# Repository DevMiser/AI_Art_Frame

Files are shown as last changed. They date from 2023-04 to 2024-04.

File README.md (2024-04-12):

On March 26, 2024, OpenAI updated its billing system to require the pre-purchase of credits in order to use the API for most users.  If you do not pre-purchase credits, you will get an API error.



















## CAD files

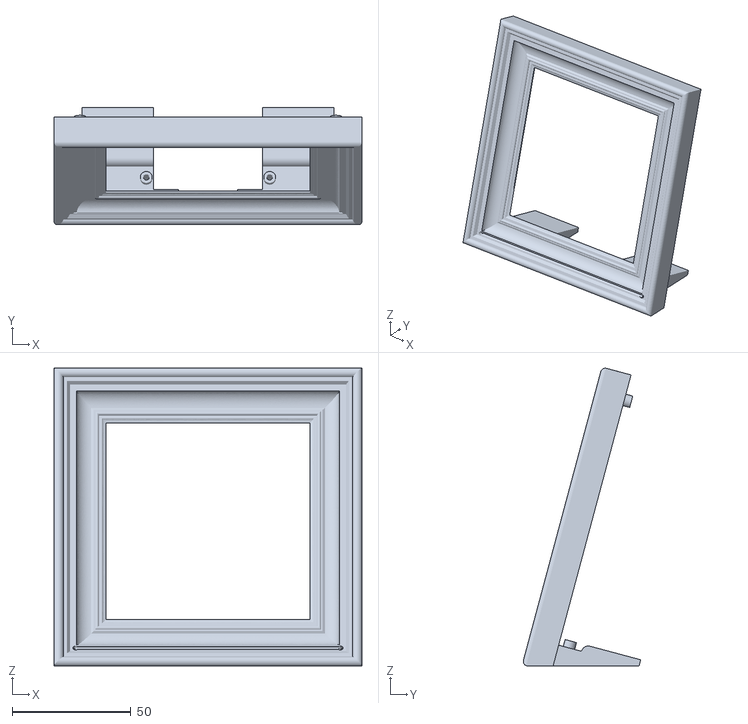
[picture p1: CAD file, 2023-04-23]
AI Art Frame.stl
129.8 x 49.5 x 125.4

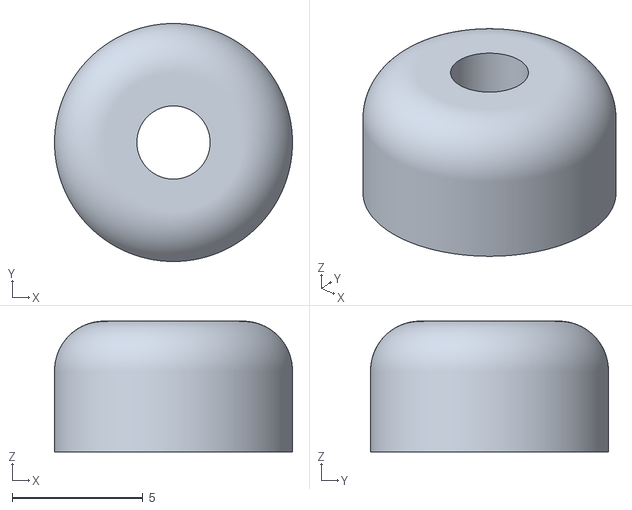
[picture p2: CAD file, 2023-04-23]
Display Stabilizer Plain.stl
9.10 x 9.10 x 5.00

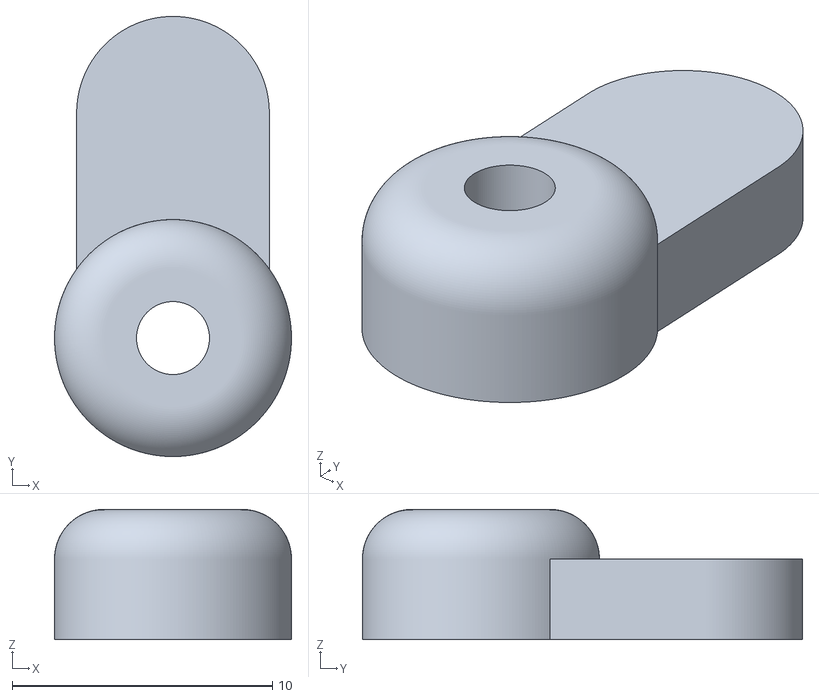
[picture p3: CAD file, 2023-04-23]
Display Stabilizer w Tab.stl
9.10 x 16.9 x 5.00

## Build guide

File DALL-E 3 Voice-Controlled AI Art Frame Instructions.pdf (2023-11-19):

## DALL-E 3 Voice-Controlled Artificial Intelligence Art Frame DIY Instructions

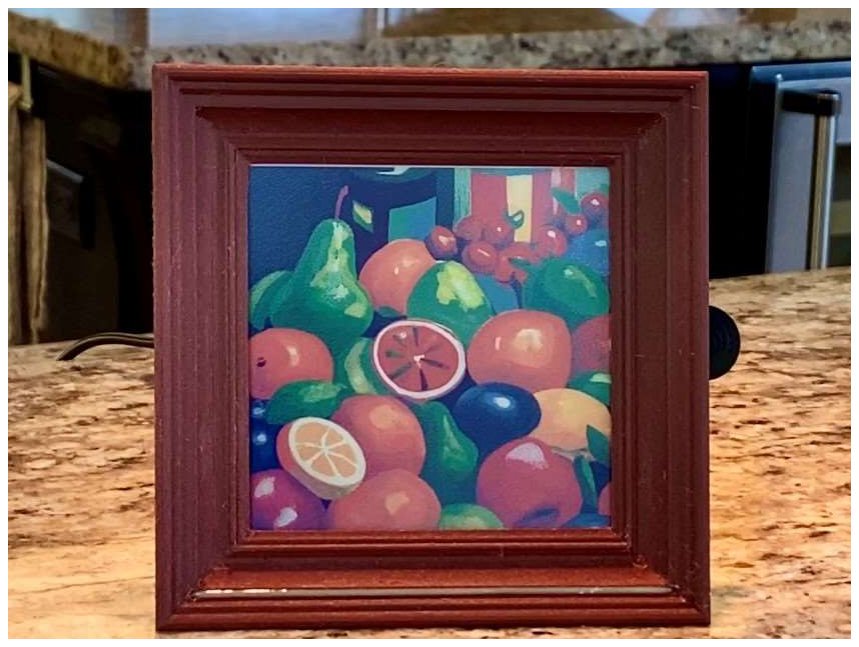
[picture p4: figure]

The DALL-E 3 Voice-Controlled AI Art Frame includes a 3D printed frame that houses a 7-color e-ink display and a Raspberry Pi 4. The RPi runs a python program that uses Picovoice Porcupine to detect a wake word; Picovoice Cobra voice activity detection to determine when the user begins and finishes speaking their image request; Picovoice Leopard to convert the spoken request into text; and OpenAI’s DALL-E 3 to convert the request to an image that is then displayed on a Pimoroni Inky Impression e-ink display.

The instructions below are for running the DALL-E 3 Voice-Controlled AI Art Frame on a Raspberry Pi 4, but it can also be run on other systems with minimal modifications. The process for obtaining access keys for DALL-E 3 and Picovoice solutions is the same regardless of the system used.

A brief video demo of the DALL-E 3 Voice-Controlled AI Art Frame is here: https://youtu.be/CKS973gClLE.

How to Run DALL-E 3 on a Raspberry Pi 4 Mini-Computer

The following steps are required to run the DALL-E3 AI image generator on your Raspberry Pi 4:

- Obtain the necessary hardware
- Create an OpenAI account and obtain your personal secret API key
- Create a Picovoice account and obtain your personal secret access key
- Follow the other steps below for preparing your Raspberry Pi and downloading the DALL-E 3 Voice-Controlled AI Art Frame

Hardware Requirements

Raspberry Pi 4 – This needs to be a Raspberry Pi 4, so that you can run the 64-bit operating system. Earlier versions of Raspberry Pis are likely to throw memory errors while running this program. The 2 GB RAM model is sufficient: https://www.adafruit.com/product/4292

Say something like “Art Frame, paint a still life of fruit,” and in a matter of
seconds an AI generated image depicting your request will ‘magically’ appear.

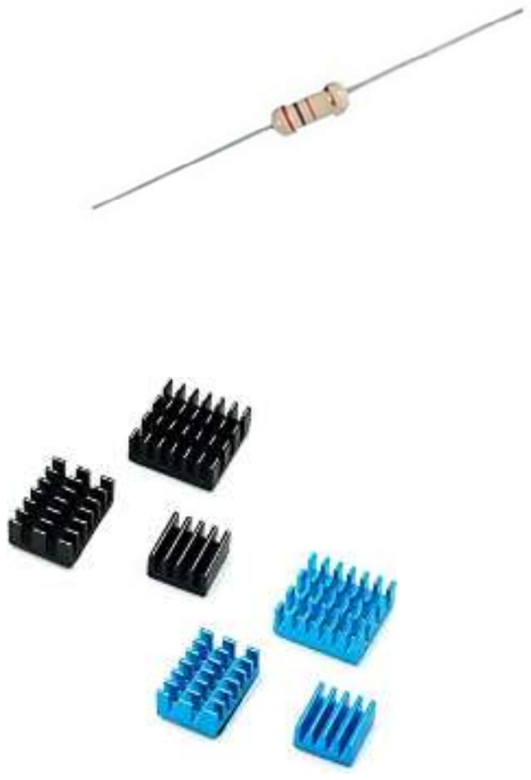
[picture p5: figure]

STLs for 3D-printing the DALL-E 3 Voice-Controlled AI Art Frame shown in the video demo are also available on this GitHub repository. See Appendix 1 for assembly instructions.

Create an OpenAI Account

Open a web browser on your PC and navigate to the OpenAI website -https://openai.com/.

In the upper right-hand corner, click on “API”

On the next screen, click on | and then follow the prompts to create your
account.

5v Power Supply – I recommend the official Raspberry Pi power supply: https://www.adafruit.com/product/4298

USB Microphone – for talking to the art frame. Any USB mic should work, and this inexpensive one is sufficient: https://www.adafruit.com/product/3367

Inky Impression 5.7” 7-color e-ink display – You can get one here: https://shop.pimoroni.com/en-us/products/inky-impression-5-7

LED Filament (300mm) – The program lights the LED filament when it detects the wake word and pulses it when the frame is responding to your request. This blue colored LED filament was used in the video demo: https://www.adafruit.com/product/5508

Resistor (220 ohm) – I used these: https://www.adafruit.com/product/2780

Heatsinks (recommended) – I used these: https://www.amazon.com/dp/B07ZLZRDXZ?psc=1&smid=A2PL6UUXJC5K5G&ref_=chk_typ_imgToDp

Obtain Your Secret OpenAI API Key

Next, on the logged-in screen, click on your Personal icon in the upper right-hand corner and then click on “View API keys”.

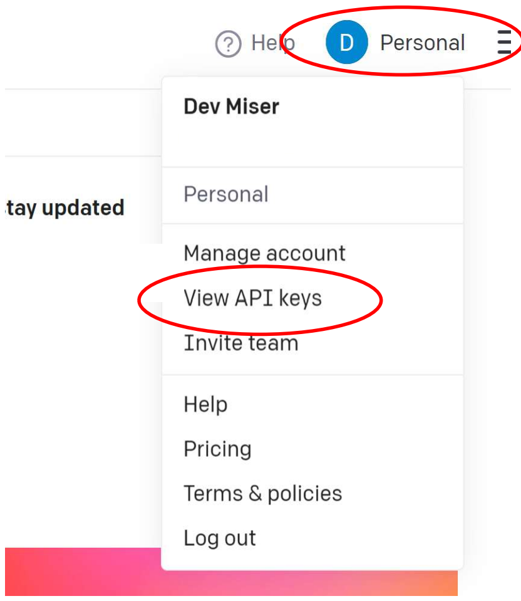
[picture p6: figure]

Then click on | to create your new secret API key. Copy your API key
and keep it in a secure location. You will need it in a later step.

Create a Picovoice Account

Create a free Picovoice account. Open a web browser and navigate to https://picovoice.ai/.
In the upper right-hand corner, click the | button and follow the prompts to open
your account.

Obtain Your Secret Picovoice Access Key

As soon as you complete your sign up, you will automatically be redirected to a page
with your secret access key. Copy your | and keep it in a secure location.
You will need it in a later step.

Prepare Your Raspberry Pi 4 to Run the Program

These instructions assume you already have a Raspberry Pi 4 set up and running. If not, set up your Raspberry Pi using the instructions found here: https://www.raspberrypi.com/tutorials/how-to-set-up-raspberry-pi/

Be certain to load the 64-bit (not the 32-bit) version of the Raspberry Pi OS when setting up your Raspberry Pi. If you use the 32-bit version, you are likely to get memory errors when running the program.

To prepare your Raspberry Pi to run the DALL-E 3 Voice-Controlled AI Art Frame, do the following:

### 1. Edit the bashrc file on your Raspberry Pi as follows:

a. Open a terminal and enter the following command to open the bashrc file:

sudo nano ~/.bashrc

b. Scroll to the bottom of the file using your keyboard and add the following lines at the end (be certain to include the #s):

# sets a location where the Raspberry Pi OS and Python can look for

# executable/configuration files

export PATH="$HOME/.local/bin:$PATH"
c. Press the CTRL and X keys simultaneously on your keyboard, then press Y and then press Enter to save the revisions to the file.
d. Then enter the following command:

sudo reboot

This will reboot your Raspberry Pi. After the reboot is completed, log back in.

### 2. Open a terminal and enter the following commands in the following order:

sudo apt update

sudo apt full-upgrade - If asked if you want to continue, enter Y and then press Enter

pip3 install --upgrade pip

sudo apt-get install portaudio19-dev - When asked if you want to continue, enter Y and then press Enter

pip3 install pyaudio

pip3 install pvrecorder

pip3 install pvporcupine

pip3 install pvcobra

pip3 install pvleopard

pip3 install schedule

pip3 install inky[rpi,example-depends]

pip3 install --upgrade openai

sudo reboot – will reboot your Raspberry Pi; log back in after the reboot.

### 3. Enable the SPI and I2C interfaces as follows:

a. Open a terminal and enter the following command:

sudo raspi-config

b. Using the arrows on your keyboard, scroll down to “3 Interface Options” and press Enter
c. Scroll down to “I4 SPI” and press Enter
d. The next screen will ask “Would you like the SPI interface to be enabled?” Select “Yes” and press Enter.
e. The next screen will state “The SPI interface in enabled”. Select “Ok” and press Enter.
f. Scroll down to “3 Interface Options” and press Enter
g. Scroll down to “I5 I2C” and press Enter
h. The next screen will ask “Would you like the ARM I2C interface to be enabled?” Select “Yes” and press Enter.
i. The next screen will state “The ARM I2C interface is enabled”. Select “Ok” and press Enter.
j. Scroll down to select “Finish” and press Enter

### 4. Download the AIArtFrame.py program and associated files by opening a terminal and

entering the following command:

git clone https://github.com/DevMiser/AI_Art_Frame.git

### 5. Modify AIArtFrame.py to include the secret API key that you previously created in

your OpenAI account and the secret access key that you created in your Picovoice account by doing the following:

a. Open a terminal and enter the following commands:

cd /home/pi/AI_Art_Frame

sudo nano AIArtFrame.py

b. Use your keyboard to scroll down to the lines that say:

openai.api_key = “put your secret API key between these quotation marks” pv_access_key= “put your secret access key between these quotation marks”

Now modify those lines to replace the portions that are italicized above with your secret OpenAI API key and your secret Picovoice access key, respectively.

c. Press the CTRL and X keys simultaneously on your keyboard, then press Y and then press Enter to save the revisions to the file.

### 6. Move the Art-Frame keyword file to the Porcupine raspberry-pi folder by entering the

following command:

mv /home/pi/AI_Art_Frame/Art-Frame_raspberry-pi.ppn /home/pi/.local/lib/ python3.9/site-packages/pvporcupine/resources/keyword_files/raspberry-pi

Note that there are two blank spaces in the above command - between "mv" and "/home" and between ".ppn" and "/home". Be sure to include them.

7. Reboot your Raspberry Pi.

Run the Program

Plug your microphone into an USB port on your Raspberry Pi 4.

To run the program, open a terminal and enter the following commands:

cd /home/pi/AI_Art_Frame

python3 ArtFrame.py

You can then wake up your DALL-E 3 Voice-Controlled AI Art Frame by saying one of the following wake words: Art-Frame, computer or Jarvis.

When the frame detects the wake word, the LED filament will illuminate. You can then make your request. For example, try:

A portrait of Albert Einstein.

A field of flowers with mountains and a rainbow in the background.

An oil painting portrait of an old fisherman.

An album cover for a punk band.

A fashion model in the style of Roy Lichtenstein.

A schooner in a storm at sunset.

Flower pedals with morning dew.

A glass bowl full of jellybeans.

A bouquet of helium balloons tied to a park bench.

After you complete your request, the LED filament will pulse on and off until DALL-E 3 processes it and your AI-generated image is displayed. Because e-ink displays work by drawing positively or negatively charged colored particles to the top of thousands of tiny oil-filled bubbles lined up against the surface of the display, this will take several seconds.

You can remove the microphone from the USB port when not in use so that it is not visible while displaying your new art in your frame.

When you are finished with the program, press the CTRL and C keys simultaneously on your keyboard and you will exit the program.

Clearing and Refreshing the E-Ink Display

In addition to requests for new images, you can instead ask the DALL-E 3 Voice-Controlled AI Art Frame to clear the current image and display a blank screen. To do this, after you awake the frame with the wake word, say “Clear the screen,” “Wipe the display”, or similar. The DALL-E 3 Voice-Controlled AI Art Frame will then cycle the screen through a series of solid colors, leaving the screen blank at the end.

The DALL-E 3 Voice-Controlled AI Art Frame is also programmed to refresh the current image each night at midnight if the power supply is plugged in. This is intended to help prevent burn-in of images on the display. When active, at midnight the DALL-E 3 Voice-Controlled AI Art Frame will cycle the screen through a series of solid colors, and then refresh to display the same image it was displaying before the refresh began.

© 2023 DevMiser. All rights reserved.

APPENDIX I

Assembling the DALL-E 3 Voice-Controlled AI Art Frame

The recommend settings for slicing the STLs for the screen are at a setting of 0.15mm with 20% infill. Print the screen face up with supports – organic supports with no interface layers if possible. Block the generation of supports for the holes in the frame for the filament and the screw holes in the four guides on the frame for the stabilizers.

In addition to the STL, pre-sliced G-Code (in a zip file) for printing the frame with organic supports is also available on this GitHub repository.

The Display Stabilizers can be 3D printed without supports.

You need two of each stabilizer – Display Stabilizer w Tabs and Display Stabilizer Plain.

In addition to the STLs, pre-sliced G-Code for printing all four stabilizers at once is also available on this GitHub repository.

The tabs can either be glued in place or attached with screws – self-tapping 2.5 mm or #4 US diameter and no more than 10mm long. See Figure 1.

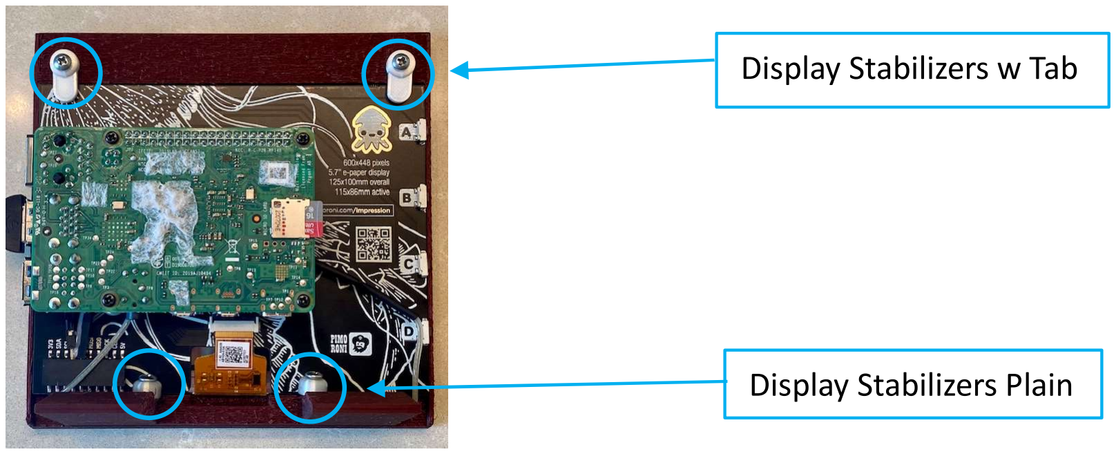
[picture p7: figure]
Display Stabilizers w Tab; Display Stabilizers Plain

The LED filament is threaded through the two holes in the printed frame and pressed gently to seat it in the channel at the bottom of the frame. You may need to gently pull the end of the filament with needlepoint pliers to thread it though the holes.

The LED filament is soldered to one end of the LED filament and the resistor. The resistor and the other end of the LED filament are then inserted into the GPIO extender on the back of the Inky Impression to GND and 4, respectively, as shown in Figure 2 below.

Figure 1

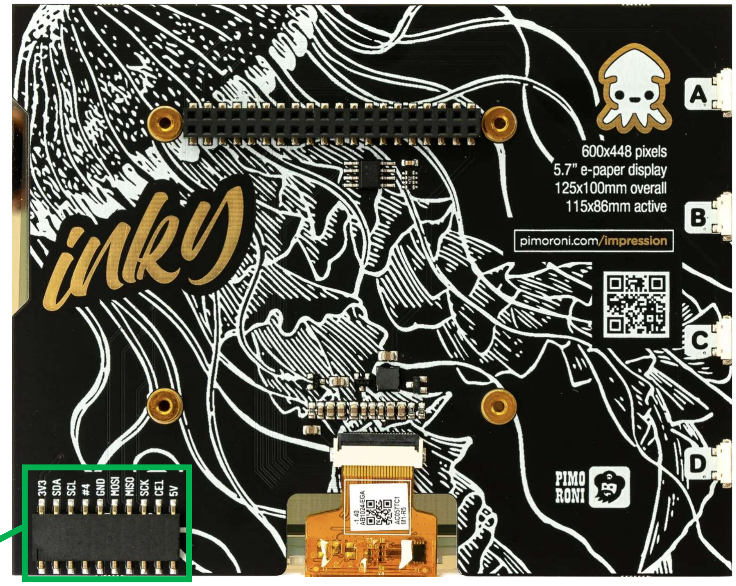
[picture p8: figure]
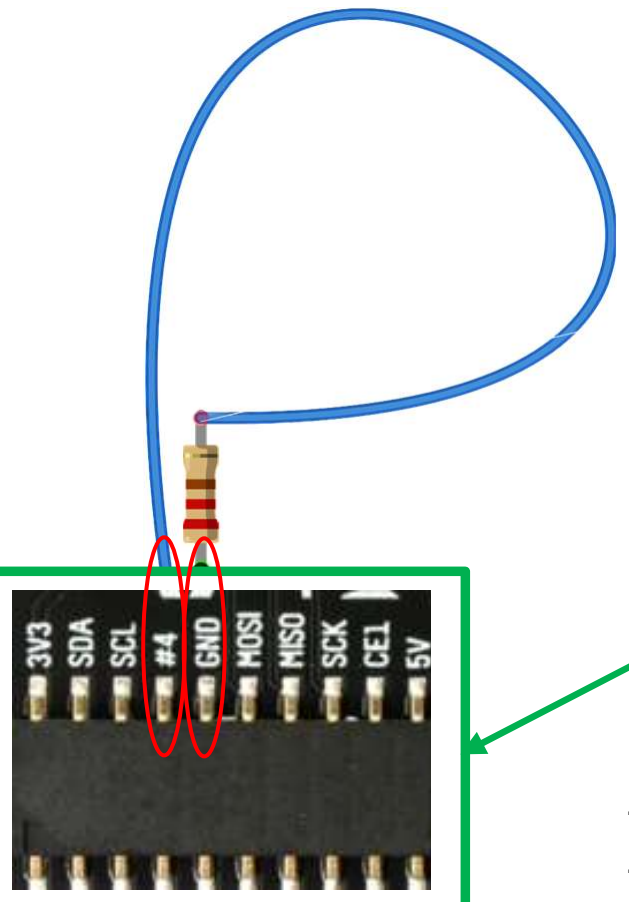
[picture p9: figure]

The LED filament will light up when the program hears the wake word and will pulse after the user finishes their query and while the assistant provides its response. The proper wiring of the LED filament and resistor is to the no. 4 GPIO connector and to the GND GPIO connector.

Figure 2

If the cord to the Power Supply interferes with how the frame sits, you can use a USB C Male to USB C Female Angle Connector.

Back of the Inky Impression Display

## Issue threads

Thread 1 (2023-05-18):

[Suggestion] Alternate services than Dall-E 2?

Spenz0r, 2023-05-18:
This is an amazing build. Could it be possible to write an alternate version where everything's the same except it connects to some sort of online Stable Diffusion or something that doesn’t require Dall-E 2? Using Dall-E 2 is very expensive and you can only generate a certain amount of images per month before paying big-time. I know in some cases the delay will be longer but the frame already has a delay anyway.

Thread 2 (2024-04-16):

RPi GPIO

EA914, 2024-04-16:
For the LED part of the code do I need to import and install RPi.GPIO? It's not in your instructions or import statements

DevMiser, 2024-04-16:
You do not need to install or import RPi.GPIO separately.  It is a part of the official Raspberry Pi OS.

EA914, 2024-04-16:
Gotcha. Thank you.

Another question: how would I make this program automatically start when plugged in? I don't want to have to manually run the script every time. Is this the .bashrc step?

DevMiser, 2024-04-16:
I recommend following the instructions in Appendix III of the instructions for Lumina and modify as appropriate: https://github.com/DevMiser/Lumina

EA914, 2024-04-17:
Thank you! That helps.

Can you also help me if I wanted the image that generates on the e-ink display to also show the prompt that generated the image to show up at the bottom of the image how would I go about doing that?

DevMiser, 2024-04-17:
I don't have the time to help you with the coding, but you can code this change yourself with a little effort.  I recommend trying Tkinter for this purpose.  If you have not used Tkinter before, there are many good tutorials that you can find easily with a web search.  You can also look at the Lumina.py code on this repository to see how I capture the prompt and display it before the generated image is displayed.  You can, of course, display the image and the prompt at the same time if you want to program it that way.

EA914, 2024-04-17:
Thank you. Perhaps you may also be interested in the modification I'm doing. I will share my github repo when I'm done with it. In addition to the DALLE-3 (you can change the model in your code by the way to use dall-e-3 now instead of dall-e-2), I'm programming another wake word of "music box". When that word is detected, the dictated prompt is transcribed and sent to SunoAI, which will generate an AI song and play it via FFMPEG through a USB speaker attached to the Raspberry Pi. After that I'll also program a wake word "robot" or something that will send the prompt to ChatGPT as a chat, and the Raspberry Pi will use OpenAI's text-to-speech and speak back the response. So all-in-one it'll be an AI song generator, an AI picture displayer, and an AI chatbot.

My question is this: from a high-level how would I program the code to have the wake words in one main script, and the separate respective AI calls in separate scripts, each one called when the wake word is detective that triggers that functionality. This way, the separate functionalities won't share or overlap resources and will run separately and not interrupt each other. Does this make sense?

Thanks so much for your prompt responses and help thus far.

DevMiser, 2024-04-18:
That sounds like a great project!

I frankly don't have much experience writing programs that call from multiple scripts.  You can use add as many keywords to the wake_word() function in my script as you would like.  From there, you can write it to do the calls based upon which keyword is detected.  If you use it to call separate scripts, you could use the Import statement to import functions, use the subprocess module, or maybe use the os.system() function.

Good luck and I look forward to seeing what you create.

EA914, 2024-04-18:
Thank you! I'll be sure to share it when I'm done.

I am having trouble with the LED filament. I have never soldered before and don't have a soldering iron. I bought this to connect the resistor to the LED filament but I'm not sure it will work: [https://a.co/d/c44NdMD](https://a.co/d/c44NdMD)

Then,one end of the LED filament goes _where_? There are these which are on the inky impressions: 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

Or do I have to "plug" the filament somewhere into the Raspberry Pi itself?: 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

If you can provide some detailed instructions I'd really appreciate it. Thank you.

EA914, 2024-04-22:
I figured the LED out, but still would like your help for a solution that doesn't involve soldering. Are there like GPIO e extenders I can use to simply "plug" the resistor end and the LED filament end into the Inky Impressions? It's kind of a loose fit and I'm not sure what my solderless options are

DevMiser, 2024-04-23:
Because I do solder, I regret that I am not familiar with any good solderless options.  You may want to learn to solder.  You can buy a decent electronics soldering kit for around $15 and there are a lot of YouTube videos to teach you how to so it.

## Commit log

2023-11-02 Delete Art-Frame_raspberry-pi.ppn
    Replacing with updated keyword file.
2023-11-19 Delete DALL-E2 Voice-Controlled AI Art Frame Instructions.pdf
    Updating Instructions
